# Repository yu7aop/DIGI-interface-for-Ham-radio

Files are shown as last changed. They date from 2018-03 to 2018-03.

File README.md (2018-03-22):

# DIGI-Interface
DIGI, PTT, CW interface, schematic, pcb, Eagle files

Project - Digi interface with 2 pots for input and output level of audio signal from PC.
Based on many different schematics, but adjusted to the needs of Radio club Zrenjanin YU7AOP.
This interface has proven to be good at working with different radio's (new and "old school":) such as:
FT901DM, FT101ZD, IC718, TS930S, FT950, FT897, some Codan's etc.

RS232 added as control port for CW and PTT. If not using CW or PTT line, simply set VOX on your RIG and use PTT via VOX on your radio.

Place interface into metal box to reduce RFI. I found on 2nd hand market defective 8 port LAN switch for about a 1$, perfect for this project.

PCB is toner-transfer method with hot Iron.
I have a lot of dual pots and PCB is adjusted for it. If you are friendly with Eagle you can change footprint for any other pot's.

Enjoy...

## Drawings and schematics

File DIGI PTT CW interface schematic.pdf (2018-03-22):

# GNDGND

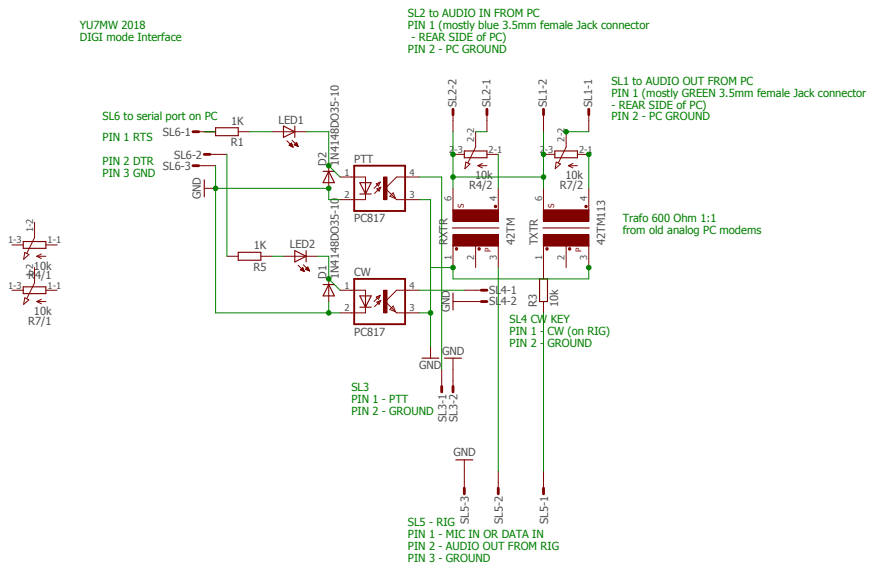
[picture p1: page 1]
GND; RXTR 1; TXTR 1; LED1; LED2; PTT; PIN 1 RTS; PIN 2 DTR PIN 3 GND; SL3 PIN 1 - PTT PIN 2 - GROUND; SL4 CW KEY; PIN 1 -; CW (on RIG); PIN 2 -; GROUND

SL2 to AUDIO IN FROM PC
PIN 1 (mostly blue 3.5mm female Jack connector
- REAR SIDE of PC)
PIN 2 - PC GROUND

DIGI mode Interface

SL1 to AUDIO OUT FROM PC
PIN 1 (mostly GREEN 3.5mm female Jack connector

SL6 to serial port on PC

Trafo 600 Ohm 1:1
from old analog PC modems

SL5 - RIG
PIN 1 - MIC IN OR DATA IN
PIN 2 - AUDIO OUT FROM RIG
PIN 3 - GROUND

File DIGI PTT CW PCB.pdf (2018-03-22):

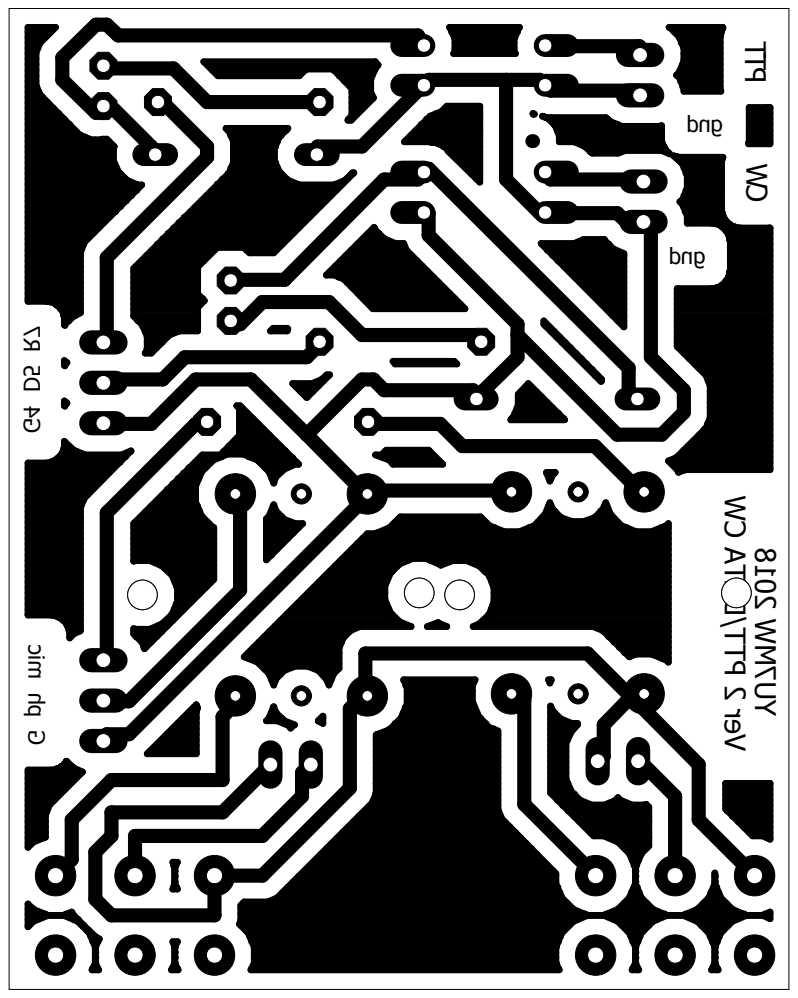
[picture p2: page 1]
G ph mic G4 D5 R7; YU7MW 2018 PTT CW

Ver 2 PTT/DATA CW

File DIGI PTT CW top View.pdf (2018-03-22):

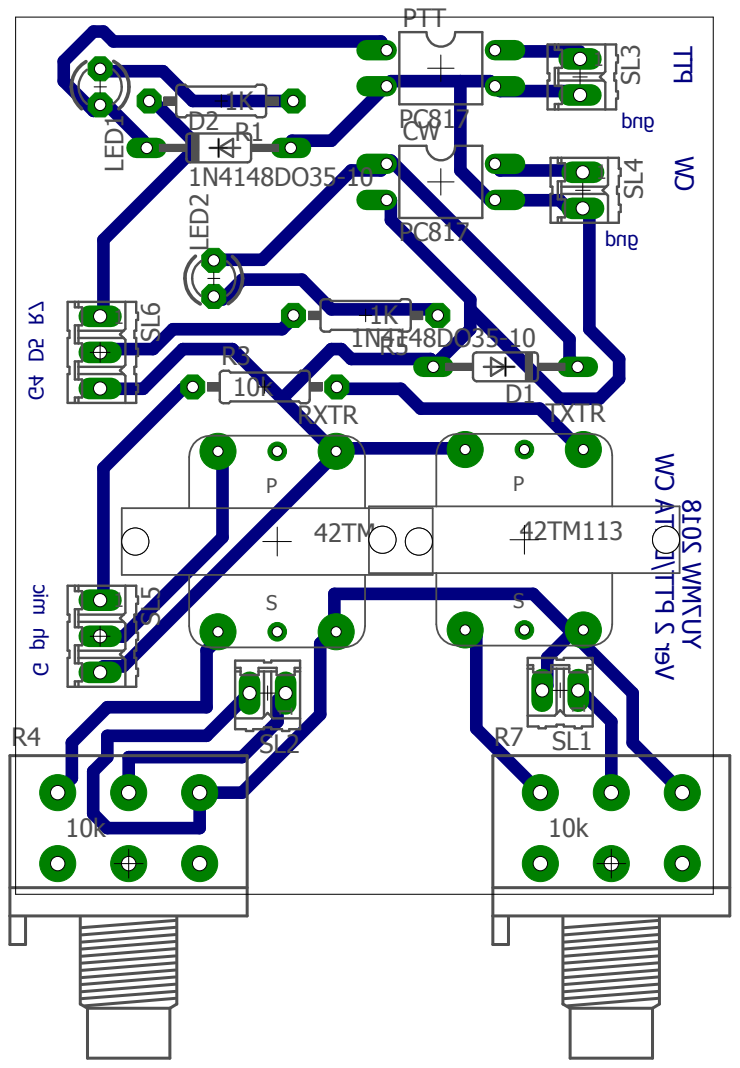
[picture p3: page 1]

Ver 2 PTT/DATA CW

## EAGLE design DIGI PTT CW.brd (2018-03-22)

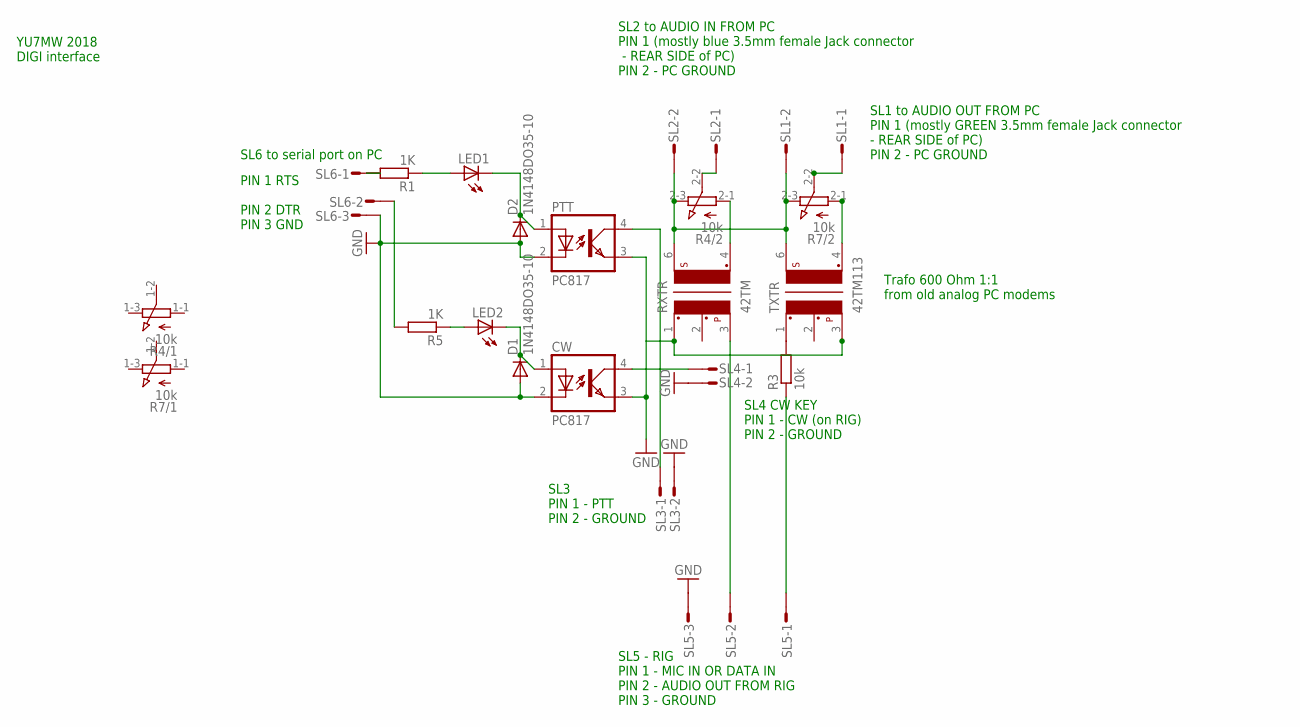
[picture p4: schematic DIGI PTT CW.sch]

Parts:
CW: PC817; DIL04
D1, D2: 1N4148DO35-10; DO35-10
LED1, LED2: LED3MM
PTT: PC817; DIL04
R1, R5: 1K; 0207/10
R3: 10k; 0207/10
R4, R7: 10k; 3RP/1610G
RXTR: 42TM
SL1, SL2, SL3, SL4: M02S; 02P
SL5, SL6: M03S; 03P
TXTR: 42TM113; 42TM

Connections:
GND: CW.2 (C), CW.3 (EMIT), D1.A, D2.A, PTT.2 (C), PTT.3 (EMIT), RXTR.1, SL3.2, SL4.2, SL5.3, SL6.3, TXTR.3
unnamed: LED1.A, R1.1
unnamed: R5.2, SL6.2
unnamed: CW.1 (A), D1.C, LED2.K (C)
unnamed: CW.4 (COL), SL4.1
unnamed: RXTR.3, SL5.2
unnamed: R3.1, SL5.1
unnamed: R4.2-2 (S), SL2.1
unnamed: R4.2-3 (E), R7.2-3 (E), RXTR.6, SL1.2, SL2.2, TXTR.6
unnamed: R3.2, TXTR.1
unnamed: R1.2, SL6.1
unnamed: R4.2-1 (A), RXTR.4
unnamed: R7.2-2 (S), SL1.1
unnamed: LED2.A, R5.1
unnamed: R7.2-1 (A), TXTR.4
unnamed: D2.C, LED1.K (C), PTT.1 (A)
unnamed: PTT.4 (COL), SL3.1

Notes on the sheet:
SL6 to serial port on PC
PIN 1 RTS PIN 2 DTR PIN 3 GND
SL5 - RIG PIN 1 - MIC IN OR DATA IN PIN 2 - AUDIO OUT FROM RIG PIN 3 - GROUND
SL3 PIN 1 - PTT PIN 2 - GROUND
SL4 CW KEY PIN 1 - CW (on RIG) PIN 2 - GROUND
SL2 to AUDIO IN FROM PC PIN 1 (mostly blue 3.5mm female Jack connector - REAR SIDE of PC) PIN 2 - PC GROUND
SL1 to AUDIO OUT FROM PC PIN 1 (mostly GREEN 3.5mm female Jack connector - REAR SIDE of PC) PIN 2 - PC GROUND
Trafo 600 Ohm 1:1 from old analog PC modems
YU7MW 2018 DIGI interface

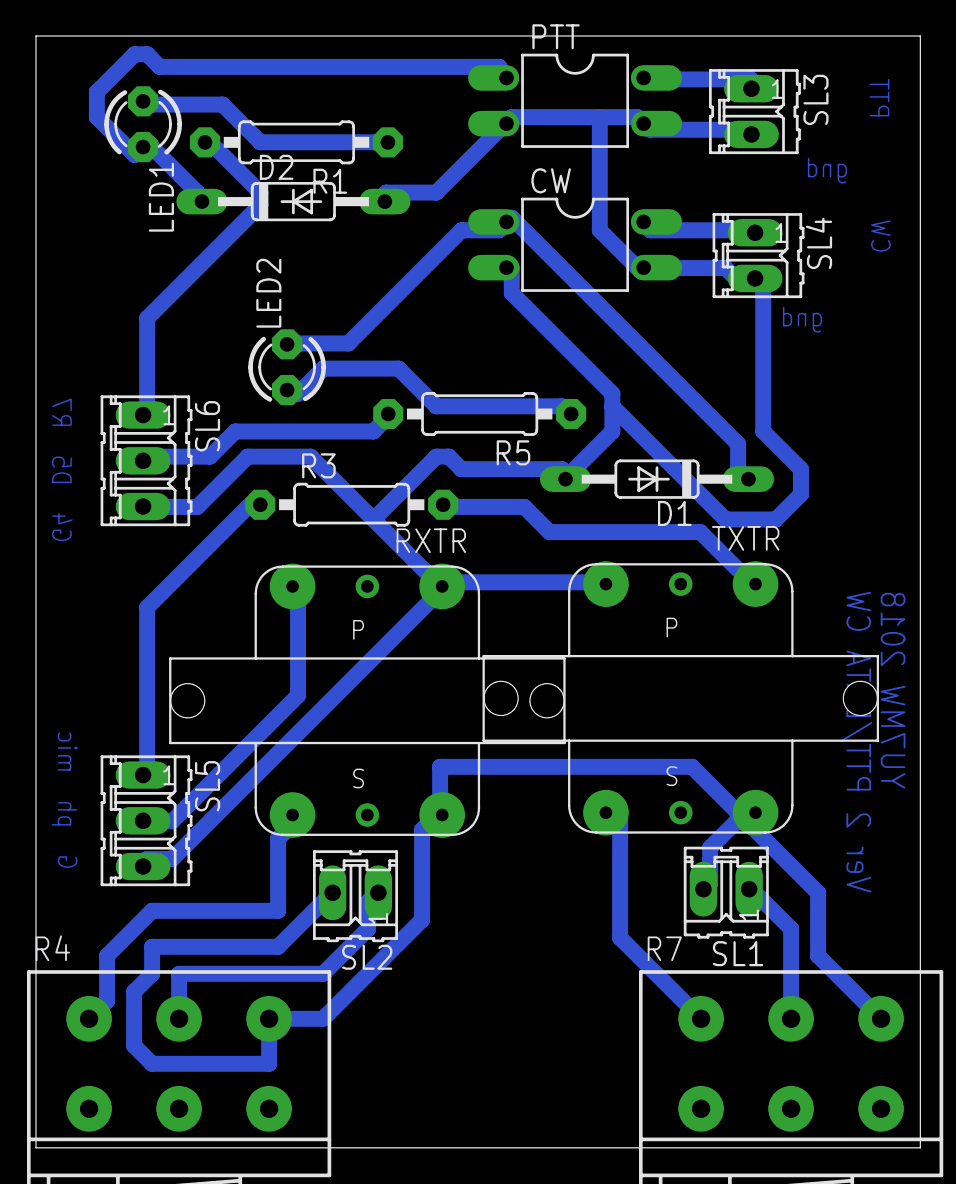
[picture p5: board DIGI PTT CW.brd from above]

Board: 2 copper layers, 49.1 x 61.8 mm, 19 parts (0 on the bottom side), 17 nets.
